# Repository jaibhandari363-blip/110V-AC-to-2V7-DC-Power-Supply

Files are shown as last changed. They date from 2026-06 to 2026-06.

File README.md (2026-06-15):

## 110V AC to 2.7V DC Isolated Power Supply

**Tools:** KiCad, LTspice  
**Topology:** Isolated flyback (IRM-10-24) + LM2596S-ADJ buck regulator  
**Output:** 2.7V DC, 200mA  

## What I Built
Designed a two-stage mains power supply from scratch. 
The first stage uses an isolated flyback module (IRM-10-24) 
to step down and isolate the 110V AC input. The second stage 
uses an LM2596S-ADJ adjustable buck regulator to regulate 
the output to 2.7V DC at 200mA.

## Design Process
- Schematic capture and component selection in KiCad
- LTspice simulation to validate circuit behavior
- BOM validation through datasheet analysis
- PCB layout with ERC/DRC verification and GND copper pour
- Bench validation of output voltage regulation and ripple

 ## Schematic
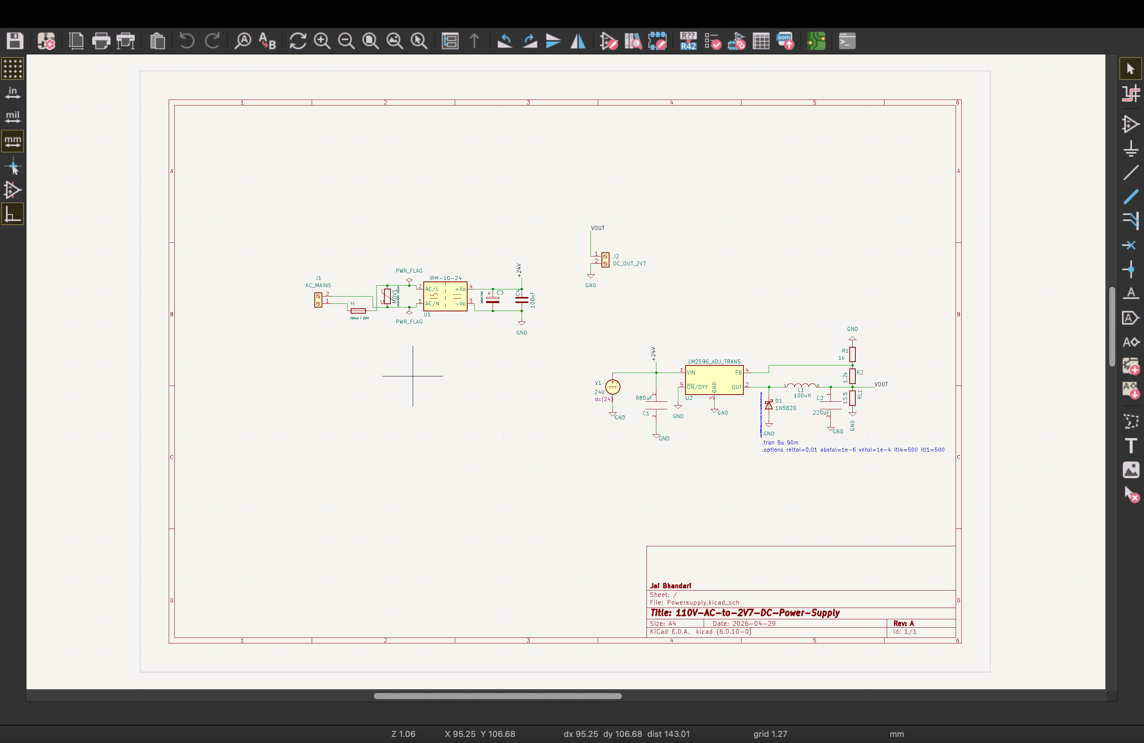
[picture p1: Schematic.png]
Schematic


## PCB Layout
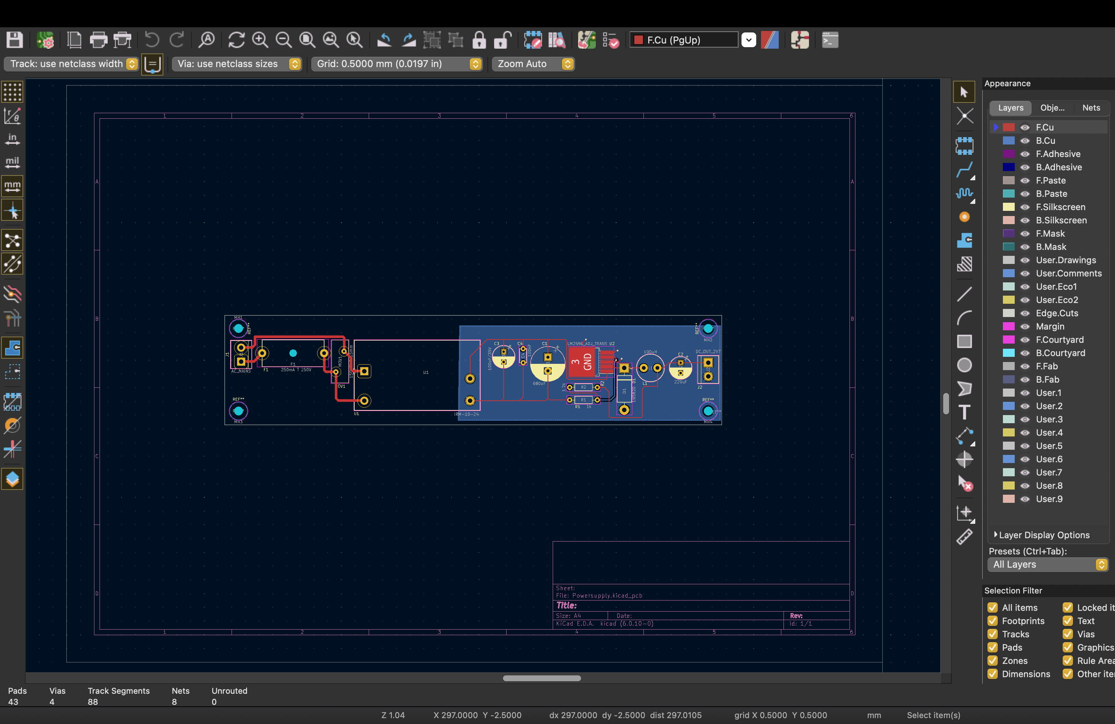
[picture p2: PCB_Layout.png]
PCB Layout


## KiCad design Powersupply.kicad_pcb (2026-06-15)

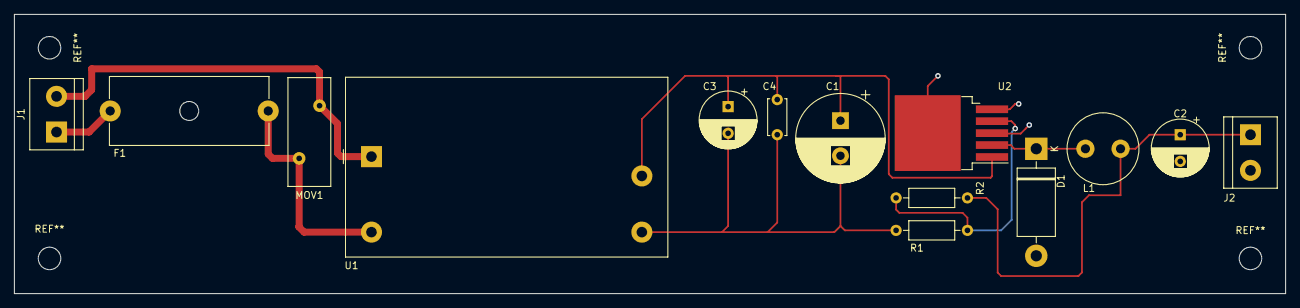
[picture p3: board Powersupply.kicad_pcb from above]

Board: 2 copper layers, 181.0 x 39.8 mm, 14 parts (0 on the bottom side), 8 nets.

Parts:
C1: 680uF; CP_Radial_D12.5mm_P5.00mm
C2: 220uF; CP_Radial_D8.0mm_P3.80mm
C3: 100uF/35V; CP_Radial_D8.0mm_P3.80mm
C4: 100nF; C_Disc_D5.0mm_W2.5mm_P5.00mm
D1: 1N5820; D_DO-201AD_P15.24mm_Horizontal
F1: 250mA T 250V; Fuseholder_Cylinder-5x20mm_Schurter_0031_8201_Horizontal_Op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
J1: AC_MAINS; TerminalBlock_bornier-2_P5.08mm
J2: DC_OUT_2V7; TerminalBlock_bornier-2_P5.08mm
L1: 100uH; L_Radial_D10.0mm_P5.00mm_Fastron_07M
MOV1: 150VRMS 15mm; RV_Disc_D15.5mm_W6.1mm_P7.5mm
R1: 1k; R_Axial_DIN0207_L6.3mm_D2.5mm_P10.16mm_Horizontal
R2: 1.2k; R_Axial_DIN0207_L6.3mm_D2.5mm_P10.16mm_Horizontal
U1: IRM-10-24; Converter_ACDC_MeanWell_IRM-10-xx_THT
U2: LM2596_ADJ_TRANS; TO-263-5_TabPin3

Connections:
/+24V: C1.1, C3.1, C4.1, U1.4 (+Vo), U2.1 (VIN)
/VOUT: C2.1, J2.1, L1.2, R2.2
GND: C1.2, C2.2, C3.2, C4.2, D1.2 (A), J2.2, R1.1, U1.3 (-Vo), U2.3 (GND), U2.5 (~ON/OFF)
unnamed: D1.1 (K), L1.1, U2.2 (OUT)
unnamed: F1.1, J1.1
unnamed: F1.2, MOV1.1, U1.2 (AC/L)
unnamed: J1.2, MOV1.2, U1.1 (AC/N)
unnamed: R1.2, R2.1, U2.4 (FB)

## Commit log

2026-06-15 Update README with schematic and PCB layout sections
    Added sections for schematic and PCB layout with images.
2026-06-15 Fix PCB Layout image filename in README
